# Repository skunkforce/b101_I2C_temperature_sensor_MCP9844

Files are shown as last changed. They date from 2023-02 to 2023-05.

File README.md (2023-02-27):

# edgy_board number b101
This design is part of the [edgy board project](https://github.com/skunkforce/edgy_boards). It provides the functionality of the digital temperature sensor MCP9844 via interfaces I2C. 

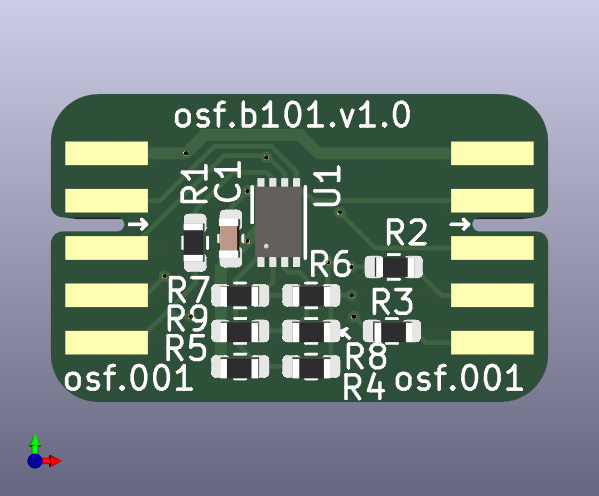
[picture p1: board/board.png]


# getting started
This repository uses submodules. After cloning use the command 

```$ git submodule update --init --recursive```

to pull the submodules before opening the project with kicad. 

# Tests
Tests can be found in [TESTS.md](TESTS.md)

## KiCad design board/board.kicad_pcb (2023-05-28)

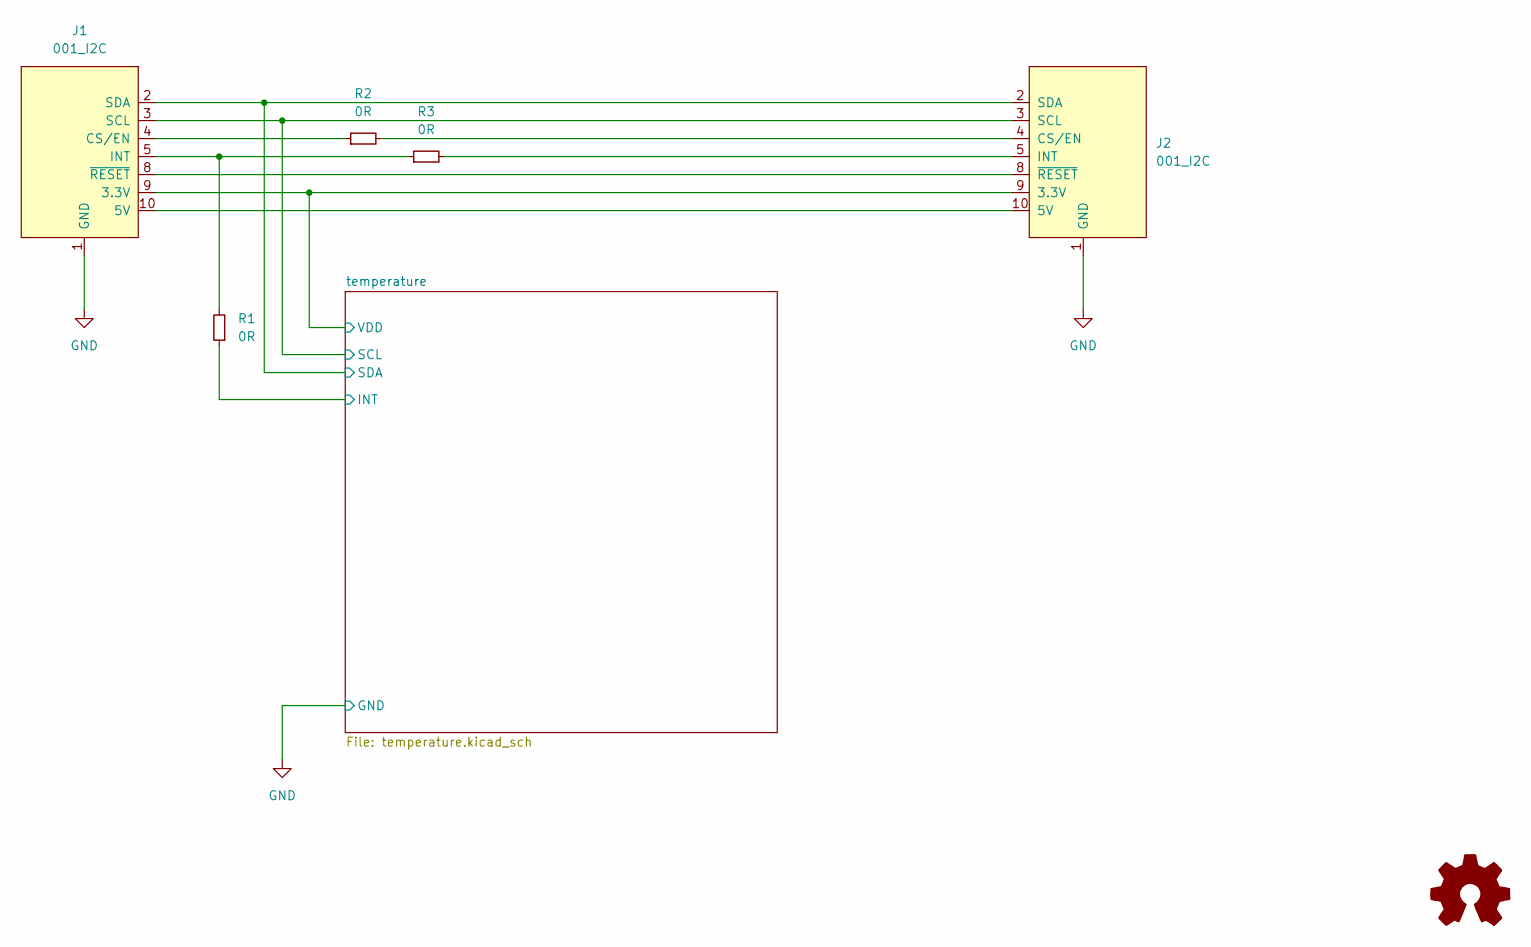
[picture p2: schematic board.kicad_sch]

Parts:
J1: 001_I2C; on_edge_2x05_device
J2: 001_I2C; on_edge_2x05_host
LOGO1: Logo_Open_Hardware_Small; OSHW-Symbol_6.7x6mm_SilkScreen
R1, R2, R3: 0R; R_0603_1608Metric

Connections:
/temperature/INT: R1.1; also elsewhere on the board
/temperature/SCL: J1.3 (SCL), J2.3 (SCL); also elsewhere on the board
/temperature/SDA: J1.2 (SDA), J2.2 (SDA); also elsewhere on the board
/temperature/VDD: J1.9 (3.3V), J2.9 (3.3V); also elsewhere on the board
GND: J1.1 (GND), J2.1 (GND); also elsewhere on the board
unnamed: J1.4 (CS/EN), R2.1
unnamed: J1.5 (INT), R1.2, R3.1
unnamed: J1.8 (~RESET), J2.8 (~RESET)
unnamed: J1.10 (5V), J2.10 (5V)
unnamed: J2.4 (CS/EN), R2.2
unnamed: J2.5 (INT), R3.2

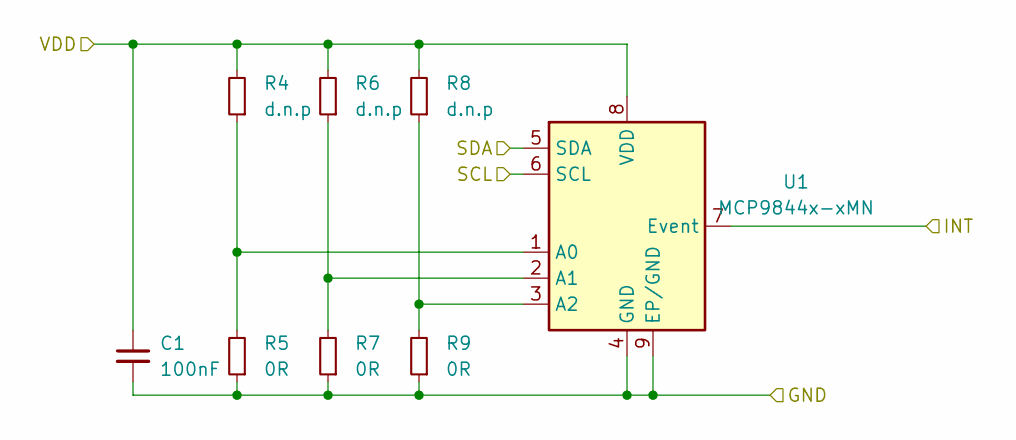
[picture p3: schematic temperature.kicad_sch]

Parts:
C1: 100nF; C_0603_1608Metric
R4, R6, R8: d.n.p; R_0603_1608Metric
R5, R7, R9: 0R; R_0603_1608Metric
U1: MCP9844x-xMN; DFN-8-1EP_3x2mm_P0.5mm_EP1.36x1.46mm

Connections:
/temperature/INT: U1.7 (Event); also elsewhere on the board
/temperature/SCL: U1.6 (SCL); also elsewhere on the board
/temperature/SDA: U1.5 (SDA); also elsewhere on the board
/temperature/VDD: C1.1, R4.2, R6.2, R8.2, U1.8 (VDD); also elsewhere on the board
GND: C1.2, R5.1, R7.1, R9.1, U1.4 (GND), U1.9 (EP/GND); also elsewhere on the board
unnamed: R4.1, R5.2, U1.1 (A0)
unnamed: R6.1, R7.2, U1.2 (A1)
unnamed: R8.1, R9.2, U1.3 (A2)

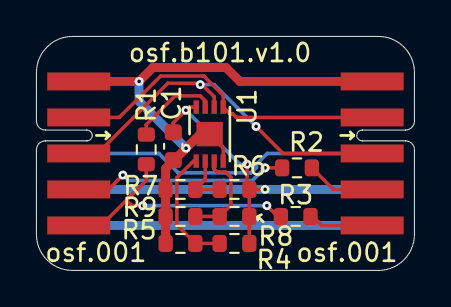
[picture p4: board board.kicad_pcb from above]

Board: 2 copper layers, 21.0 x 13.0 mm, 14 parts (1 on the bottom side), 14 nets.

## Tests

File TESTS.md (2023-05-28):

# communication test
## setup
Connect to b018 via I2C connector. Run the following micropython code:
```python
import machine
import utime
sda = machine.Pin(18)
scl = machine.Pin(19)
i2c=machine.I2C(1,sda=sda, scl=scl, freq=400000)
devices = i2c.scan()
if devices:
    for d in devices:
        print(hex(d))

while True:
    i2c.writeto(0x18,b'\x05')
    res=i2c.readfrom(0x18,2)
    print(hex(res[0]))
    print(hex(res[1]))
    utime.sleep(1)
    
```

Verify that the values in the temperature register at address 5 change with changing temperature.
## results
Values of the temperature register change when I change the temperature of the chip (by heating it with a hot air soldering tool).
